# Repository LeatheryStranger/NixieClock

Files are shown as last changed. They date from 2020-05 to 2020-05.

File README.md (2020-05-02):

# NixieClock
Yet another Nixie Clock build
I got enamored with Nixie tubes as, it seems, every other tinkerer has these days.  COVID-19 finally pushed me to start on this project, as I figured I should at least learn something during this strange time.  This repository contains everything you need to create a simple Nixie Clock that will keep time in one timezone without worrying about daylight savings.
# Repository Structure
* Hardware
  * BoM - Bill of Materials
  * 3D Models - Files to print 3d printed parts
* Instructions - Build instructions and Tips
* Firmware - Code to control clock
# References
A big thank you to Tony and his excellent parts available at https://www.tindie.com/stores/tonyp7/

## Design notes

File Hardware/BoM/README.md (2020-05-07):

| Part Number  |Quantity|Manufacturer|Description|Source|
|---|---|---|---|---|
|N/A | 4 | Yourself | Tonyp7 Serial Nixie Driver  | you can find the plans [here](https://github.com/tonyp7/SerialNixieDriver)|
|  IN-12a |4 | N/A  |  Nixie Tubes |  [Tubes-Store](https://tubes-store.com) |
| PL31A-P  |  4 | Soviet |  Nixie Tube Socket | [Tubes-Store](https://tubes-store.com)  |
| 63391-1-ND | 48  | 	TE Connectivity AMP Connectors |  Quick connects for nixie sockets | [Digikey](https://www.digikey.com/products/en?keywords=63391-1-ND)  |
| 0721248989307|1|[Plusivo](www.plusivo.com)| 30AWG hookup wire for Nixie connections| [Amazon Page](https://www.amazon.com/gp/product/B07T1MR9C4)|
|WK106| 1| Elenco | 22Gauge solid wire for all other connections| | just easier to use for and a bit more robust for higher current draw before voltage boost|
| 3500 | 1 | [Adafruit](www.adafruit.com) | Trinket M0 Microcontroller | [Adafruit Trinket M0](https://www.adafruit.com/product/3500#description)|
| 3013 | 1 | [Adafruit](www.adafruit.com) | DS3231 RTC breakout | [Adafruit DS3231](https://www.adafruit.com/product/3013)|
| CR1220 | 1 | [Digikey](www.digikey.com) |  1220 Coin Cell 3v Battery | [Digikey CR1220](https://www.digikey.com/product-detail/en/panasonic-bsg/CR1220/P033-ND/269740) |
| D24V5F3 | 1 | [Pololu](www.pololu.com) | Step down voltage regulator | [Pololu](https://www.pololu.com/product/2842)|
| N/A | 1 | Idyl.io | 170V High Voltage Nixie Power Supply | [Tindie](https://www.tindie.com/products/tonyp7/170v-high-voltage-nixie-power-supply/#product-description) |
|721AFMS | 1 | [switchcraft.com](www.switchcraft.com) | DC jack (fits psu below) | [Digikey](https://www.digikey.com/products/en?keywords=SC3721-ND) |
|  	GST18A12-P1J | 1 | [Meanwell](https://www.meanwellusa.com/) | AC/DC power supply 12V/18W | [Digikey](https://www.digikey.com/products/en?keywords=1866-2052-ND)|
| N/A | 22 | N/A | M3x6mm Machine Screws | [Bolt Depot](https://www.boltdepot.com/Catalog.aspx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) |
| N/A | 20 | N/A | M2.5x4mm Machine Scews | [Bolt Depot](https://www.boltdepot.com/Catalog.aspx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)|
| 1365868 | 1 | [Loctite](https://www.loctiteproducts.com/en.html?utm_source=loctite.com&utm_medium=redirect&utm_campaign=301_redirect) | 5-Minute Epoxy | Home Depot has it |

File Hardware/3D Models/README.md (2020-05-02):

# STL Files

These Files should allow you to print your own enclosure.  I printed mine on a Formlabs Form 2, so I've not tested their printability with any FDM printers YRMV.

| Part Name | Description | Comments |
| --- | --- | --- |
| FrontFacade | Faceplate and Mount for NixieSocketHolder | M3 tap for mounting holes, Glue to LeftWall/RightWall/Top |
| LeftWall | Sidewall for Enclosure, includes hole for ON/OFF switch | M3 tap for mounting holes |
| RightWall | Sidewall for Enclosure | M3 tap for mounting holes |
| NixieSocketHolder |  mount for IN-12 sockets | Mounting holes should fit M3, need to drill and tap holes to mount sockets, guess what? I used M3 |
|LeftBackWall | Back and Bottom, includes mounting holes for LeftWall/RightWall, and hole for DC power socket (see BoM) | Need to drill out holes (wrong size for M3 mounting screws |
|RightBackWall | Back and Bottom, includes mounting holes for LeftWall/RightWall, and hole for DC power socket (see BoM) | Need to drill out holes (wrong size for M3 mounting screws |
| Top | Grill for top | Glue to LeftWall/RightWall to make an arch, BONDIC works great |

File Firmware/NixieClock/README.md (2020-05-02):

# NixieClock Firmware
## Overview
This little sketch pulls from a small list of projects to create a clock that should maintain the correct time for years thanks to the battery operated RTC module.  In order to set that to the correct time, Please go to the setup folder to find the code I used to do that (wifi NTP setup).  It takes UTC unix time from the RTC, then using the excellent Timezone library from JChristesens, converts it to the local time.  The parses the time into individual digits and outputs those to the tubes.  Every 15 minutes or so it cycles through all the digits in the clock to clean any deposits off of them.  

## Dependencies
* RTCLib - For this project I used a [DS3231](https://learn.adafruit.com/adafruit-ds3231-precision-rtc-breakout/overview) from Adafruit, which uses this [RTCLib](https://github.com/adafruit/RTClib)
* Timezone - You can find JChristesens Timezone library [here](https://github.com/JChristensen/Timezone)
* SerialNixieDriver - Excellent little library, but afaik only useful if you use the designs for the [Serial Nixie Driver](https://github.com/tonyp7/SerialNixieDriver)

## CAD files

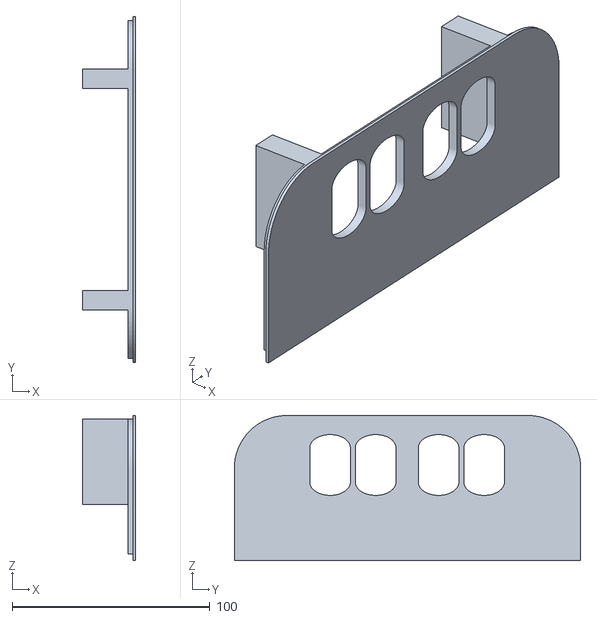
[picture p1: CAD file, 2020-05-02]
Hardware/3D Models/FrontFacade.stl
26.8 x 175.0 x 73.2

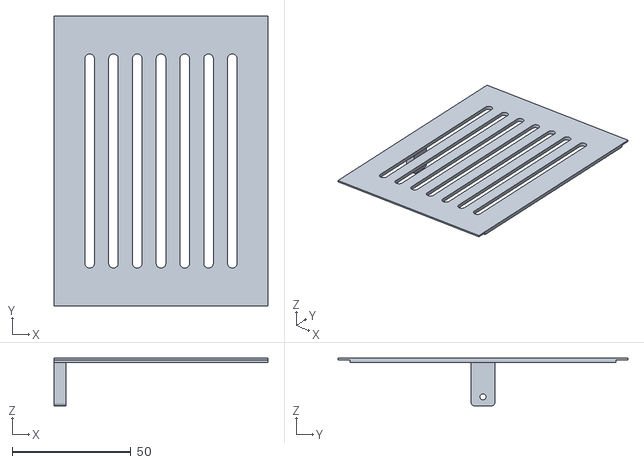
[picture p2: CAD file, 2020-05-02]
Hardware/3D Models/Top.stl
90.0 x 121.8 x 20.0

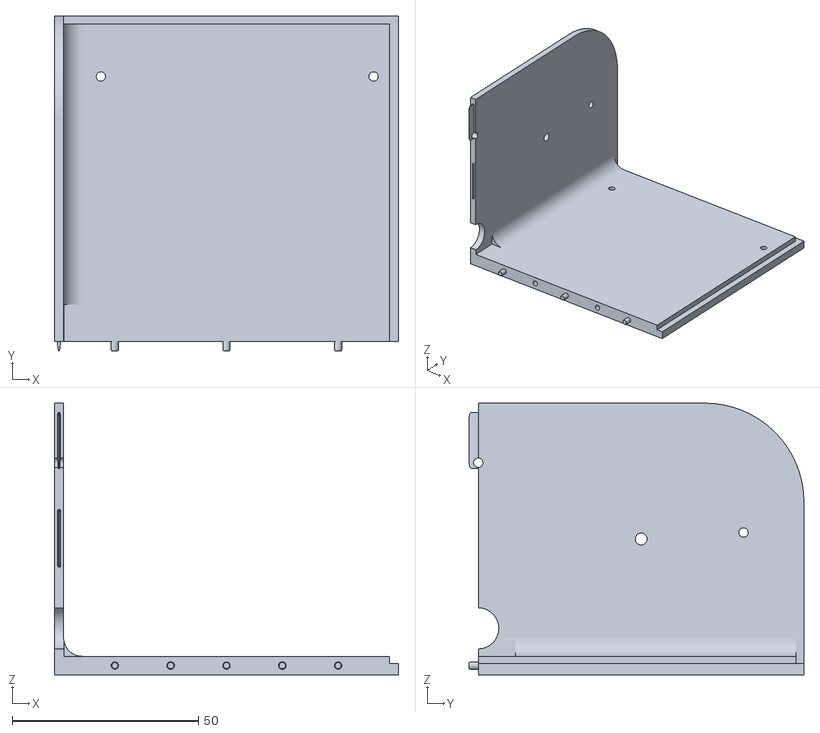
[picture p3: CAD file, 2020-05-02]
Hardware/3D Models/LeftBackWall.stl
92.5 x 90.0 x 73.0

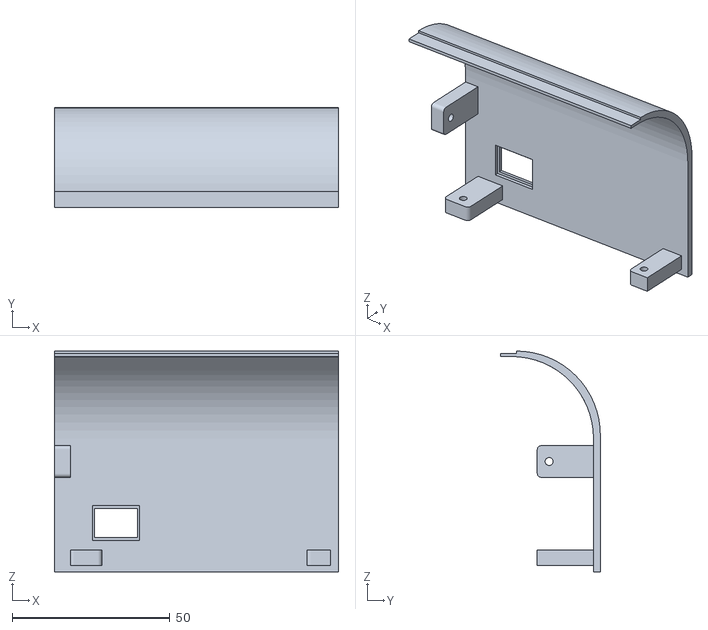
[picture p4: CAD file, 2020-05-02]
Hardware/3D Models/LeftWall.stl
90.0 x 31.6 x 70.0

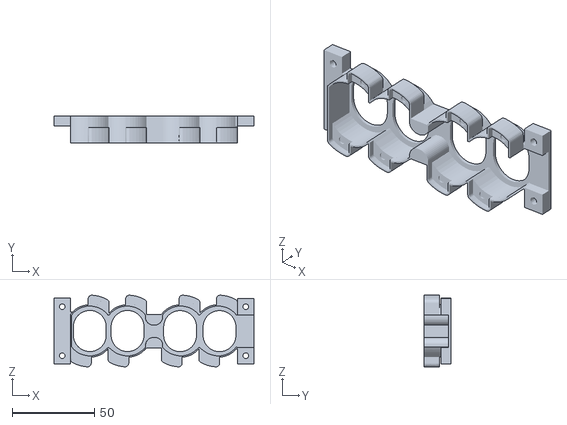
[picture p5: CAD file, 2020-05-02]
Hardware/3D Models/NixieSocketHolder.stl
121.8 x 16.4 x 43.7

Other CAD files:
Hardware/3D Models/RightWall.stl
Hardware/3D Models/RightBackWall.stl

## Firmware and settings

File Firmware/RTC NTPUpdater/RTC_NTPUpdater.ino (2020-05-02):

/*

 Udp NTP Client

 Get the time from a Network Time Protocol (NTP) time server
 Demonstrates use of UDP sendPacket and ReceivePacket
 For more on NTP time servers and the messages needed to communicate with them,
 see http://en.wikipedia.org/wiki/Network_Time_Protocol

 created 4 Sep 2010
 by Michael Margolis
 modified 9 Apr 2012
 by Tom Igoe

 This code is in the public domain.

 */

#include <SPI.h>
#include <WiFiNINA.h>
#include <WiFiUdp.h>
#include <RTClib.h>

int status = WL_IDLE_STATUS;
#include "arduino_secrets.h" 
///////please enter your sensitive data in the Secret tab/arduino_secrets.h
char ssid[] = SECRET_SSID;        // your network SSID (name)
char pass[] = SECRET_PASS;    // your network password (use for WPA, or use as key for WEP)
int keyIndex = 0;            // your network key Index number (needed only for WEP)

unsigned int localPort = 2390;      // local port to listen for UDP packets

IPAddress timeServer(129, 6, 15, 28); // time.nist.gov NTP server

RTC_DS3231 rtc; //Real Time Clock Instance

const int NTP_PACKET_SIZE = 48; // NTP time stamp is in the first 48 bytes of the message

byte packetBuffer[ NTP_PACKET_SIZE]; //buffer to hold incoming and outgoing packets

// A UDP instance to let us send and receive packets over UDP
WiFiUDP Udp;

void setup() {
  // Open serial communications and wait for port to open:
  Serial.begin(9600);
  while (!Serial) {
    ; // wait for serial port to connect. Needed for native USB port only
  }

  // check for the WiFi module:
  if (WiFi.status() == WL_NO_MODULE) {
    Serial.println("Communication with WiFi module failed!");
    // don't continue
    while (true);
  }

  String fv = WiFi.firmwareVersion();
  if (fv < WIFI_FIRMWARE_LATEST_VERSION) {
    Serial.println("Please upgrade the firmware");
  }

  // attempt to connect to Wifi network:
  while (status != WL_CONNECTED) {
    Serial.print("Attempting to connect to SSID: ");
    Serial.println(ssid);
    // Connect to WPA/WPA2 network. Change this line if using open or WEP network:
    status = WiFi.begin(ssid, pass);

    // wait 10 seconds for connection:
    delay(10000);
  }

  Serial.println("Connected to wifi");
  printWifiStatus();

  Serial.println("\nStarting connection to server...");
  Udp.begin(localPort);
}

void loop() {
  sendNTPpacket(timeServer); // send an NTP packet to a time server
  // wait to see if a reply is available
  delay(1000);
  if (Udp.parsePacket()) {
    Serial.println("packet received");
    // We've received a packet, read the data from it
    Udp.read(packetBuffer, NTP_PACKET_SIZE); // read the packet into the buffer

    //the timestamp starts at byte 40 of the received packet and is four bytes,
    // or two words, long. First, esxtract the two words:

    unsigned long highWord = word(packetBuffer[40], packetBuffer[41]);
    unsigned long lowWord = word(packetBuffer[42], packetBuffer[43]);
    // combine the four bytes (two words) into a long integer
    // this is NTP time (seconds since Jan 1 1900):
    unsigned long secsSince1900 = highWord << 16 | lowWord;
    Serial.print("Seconds since Jan 1 1900 = ");
    Serial.println(secsSince1900);

    // now convert NTP time into everyday time:
    Serial.print("Unix time = ");
    // Unix time starts on Jan 1 1970. In seconds, that's 2208988800:
    const unsigned long seventyYears = 2208988800UL;
    // subtract seventy years:
    unsigned long epoch = secsSince1900 - seventyYears;
    // print Unix time and update the RTC:
    Serial.println(epoch);
    rtc.adjust(epoch);
    
    
  }
  // wait ten seconds before asking for the time again
  delay(10000);
}

/


}


void printWifiStatus() {
  // print the SSID of the network you're attached to:
  Serial.print("SSID: ");
  Serial.println(WiFi.SSID());

  // print your board's IP address:
  IPAddress ip = WiFi.localIP();
  Serial.print("IP Address: ");
  Serial.println(ip);

  // print the received signal strength:
  long rssi = WiFi.RSSI();
  Serial.print("signal strength (RSSI):");
  Serial.print(rssi);
  Serial.println(" dBm");
}

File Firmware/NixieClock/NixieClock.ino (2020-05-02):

#include "RTClib.h"   //Adafruit fork for DS3231 support
#include "SerialNixieDriver.h" //from user TonyP7
#include "Timezone.h"
#include "Wire.h" 

//Necessary Classes for Sketch
RTC_DS3231 rtc;
SerialNixieDriver driver;

//Time Variables
time_t utc;   //unix
time_t local; //unix
DateTime nowish;  //strings

// US Eastern Time Zone (New York, Detroit)
TimeChangeRule myDST = {"EDT", Second, Sun, Mar, 2, -240};    //Daylight time = UTC - 4 hours
TimeChangeRule mySTD = {"EST", First, Sun, Nov, 2, -300};     //Standard time = UTC - 5 hours
Timezone myTZ(myDST, mySTD);

//Individual Characters for Nixie Tubes
int MinuteOnes = 0;
int MinuteTens = 0;
int HourOnes = 0;
int HourTens = 0;

//Settings for SoftwareSerial to Nixies
int rckPin = 1;
int sckPin = 3;
int dataPin = 4;

//Nixie Clock Variables
uint8_t TimeVal[4]; //Array for sending Values
const uint8_t NB_TUBES = 4;  //Nuber of tubes
int i = 0;  //count for nixie de-poisoning nixies

void setup () {

//Setup Debugging
  Serial.begin(9600);
  delay(3000);

// Setting up SerialNixieDriver
  driver.begin(rckPin, sckPin, dataPin, 0, false);

//RTC Setup
  if (! rtc.begin()) {
    Serial.println("Couldn't find RTC");
    while (1);
  }

  //Setting EOSC bit to 0 to enable battery operation on RTC DS3231
  Wire.begin();
  Wire.beginTransmission(0x68);
  Wire.write(0xE);
  Wire.write(0x00);
  Wire.endTransmission();
  
  //If battery dies on Nixie reset to approximate UTC time from when script was compiled.
  if (rtc.lostPower()) {   //rtc.lostPower()
    ResetClock();
  }
}

void loop () {
//Get Current time from RTC
  DateTime utcnow = rtc.now();
    
//Debugging Print to serial for reference   
  Serial.print(utcnow.hour(), DEC);
  Serial.print(':');
  Serial.print(utcnow.minute(), DEC); 
  Serial.print("Temperature: ");
  Serial.print(rtc.getTemperature());
  Serial.println(" C");
  Serial.println();

//Changing UTC to Local
  local = myTZ.toLocal(utcnow.unixtime());
  
//Splitting Time for Array
  HourOnes = hour(local) % 10;
  HourTens = ((hour(local)/10) % 10);
  MinuteOnes = minute(local) % 10;
  MinuteTens = (minute(local)/10) % 10;

//Debugging time split to serial
  Serial.print(HourTens);
  Serial.print(HourOnes);
  Serial.print(MinuteTens);
  Serial.print(MinuteOnes);
  Serial.println();

//Setup and send array to nixies
  TimeVal[0] = HourTens;
  TimeVal[1] = HourOnes;
  TimeVal[2] = MinuteTens;
  TimeVal[3] = MinuteOnes;
  driver.send(TimeVal, NB_TUBES);

//Nixie digit cycle for cleaning
  if (i >= 900){
    for (uint8_t j = 0; j < 10; j++) {
      for (uint8_t k = 0; k < 4; k++) {
        TimeVal[k] = j;
      }
      driver.send(TimeVal, NB_TUBES);
      delay(1000);
    }
    i = 0;
    return;
  }
  i++;
  delay(1000);
}
void ResetClock() {
  Serial.println("RTC lost power, lets set the time!");

  rtc.adjust(DateTime(F(__DATE__), F(__TIME__)));
  nowish = rtc.now();
  utc = myTZ.toUTC(nowish.unixtime());
  rtc.adjust(utc);
}

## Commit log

2020-05-01 Cleanup Changes
    No serial input to reset clock, pulled ResetClock() into its own function.
    [NixieClock.ino]
2020-05-02 Files to 3D Print Nixie Enclosure
    [FrontFacade.stl, LeftBackWall.stl, LeftWall.stl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]
